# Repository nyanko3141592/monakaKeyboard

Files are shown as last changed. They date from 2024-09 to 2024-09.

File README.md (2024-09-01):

# monakaKeyboard

monakaKeyboard は、自作キーボードのプロジェクトです。このリポジトリには、キーボードの設計ファイル、ファームウェア、キーキャップデザイン、ケースの 3D モデルなどが含まれています。

## プロジェクト構成

```
.
├── 3DModel
│   ├── Case
│   │   ├── bottomboard.stl
│   │   └── topboard.stl
│   └── keycap
│       ├── alphabet_keycap.stl
│       └── symbol_keycap.stl
├── 3x7
├── README.md
└── choco002
    ├── keyboard.json
    ├── keymaps
    │   └── default
    │       └── keymap.c
    └── readme.md
```

### 3DModel

- `Case/`  
  ケースの 3D モデルが含まれています。

  - `bottomboard.stl` - 底板の 3D モデル
  - `topboard.stl` - 上部パネルの 3D モデル

- `keycap/`  
  キーキャップの 3D モデルが含まれています。
  - `alphabet_keycap.stl` - アルファベットキー用キーキャップ
  - `symbol_keycap.stl` - シンボルキー用キーキャップ

### 3x7

3x7 キー配列の設計データが含まれています。
3x7/DisliKey.kicad_pro から kicad で開いて Gerber ファイルを発注することができます。

### choco002

QMK ファームウェアの設定ファイルが含まれています。

- `keyboard.json`  
  キーボードの設定ファイルです。

- `keymaps/`  
  キーマップの定義が含まれています。
  - `default/keymap.c` - デフォルトのキーマップ定義

## 使い方

### 3D モデルの印刷

`3DModel`ディレクトリ内の STL ファイルを 3D プリンターで印刷してください。ケースとキーキャップを含めた全ての部品を印刷することで、物理的なキーボードを組み立てることができます。

### QMK ファームウェアの設定

`choco002`ディレクトリ内のファイルを使用して、QMK ファームウェアをビルドおよびフラッシュします。キーマップはデフォルト設定で使用できますが、`keymap.c`ファイルを編集することでカスタマイズが可能です。

1. QMK CLI をインストールしていない場合は[こちら](https://docs.qmk.fm/#/ja/getting_started_build_tools)からインストールしてください。
2. `choco002`ディレクトリに移動し、次のコマンドを実行します。

   ```
   qmk compile -kb choco002 -km default
   qmk flash -kb choco002 -km default
   ```

## ライセンス

このプロジェクトは、商用利用を除く目的での使用、改変、および出力を許可します。

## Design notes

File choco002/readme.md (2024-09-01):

# choco002

choco002

*A short description of the keyboard/project*

* Keyboard Maintainer: [Naoki Takahashi / 電電猫猫](https://github.com/Naoki Takahashi / 電電猫猫)
* Hardware Supported: *The PCBs, controllers supported*
* Hardware Availability: *Links to where you can find this hardware*

Make example for this keyboard (after setting up your build environment):

    make choco002:default

Flashing example for this keyboard:

    make choco002:default:flash

See the [build environment setup](https://docs.qmk.fm/#/getting_started_build_tools) and the [make instructions](https://docs.qmk.fm/#/getting_started_make_guide) for more information. Brand new to QMK? Start with our [Complete Newbs Guide](https://docs.qmk.fm/#/newbs).

## Bootloader

Enter the bootloader in 3 ways:

* **Bootmagic reset**: Hold down the key at (0,0) in the matrix (usually the top left key or Escape) and plug in the keyboard
* **Physical reset button**: Briefly press the button on the back of the PCB - some may have pads you must short instead
* **Keycode in layout**: Press the key mapped to `QK_BOOT` if it is available

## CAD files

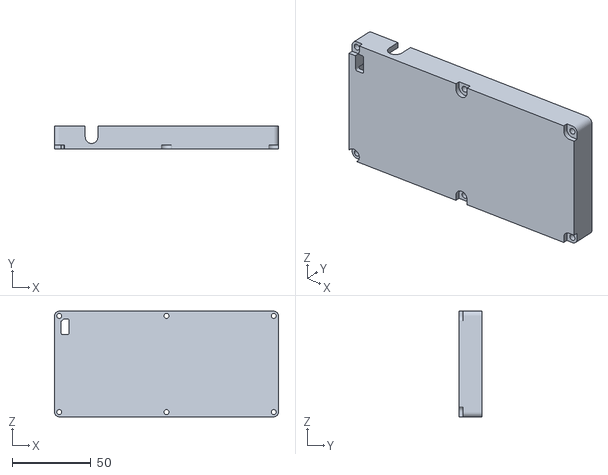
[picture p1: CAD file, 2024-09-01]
3DModel/Case/bottomboard.stl
142.1 x 14.5 x 67.0

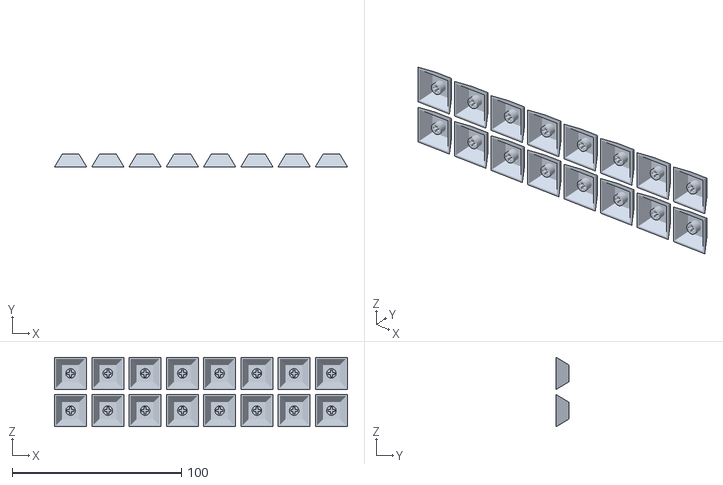
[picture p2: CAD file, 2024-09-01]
3DModel/keycap/symbol_keycap.stl
173.0 x 7.50 x 41.0

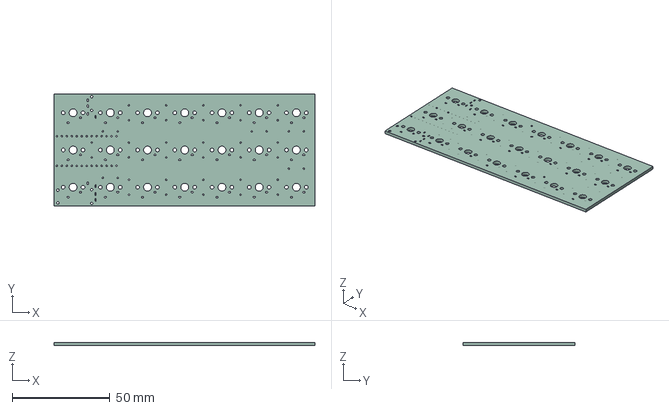
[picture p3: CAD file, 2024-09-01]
3x7/DisliKey.step
133.6 x 57.2 x 1.60 mm

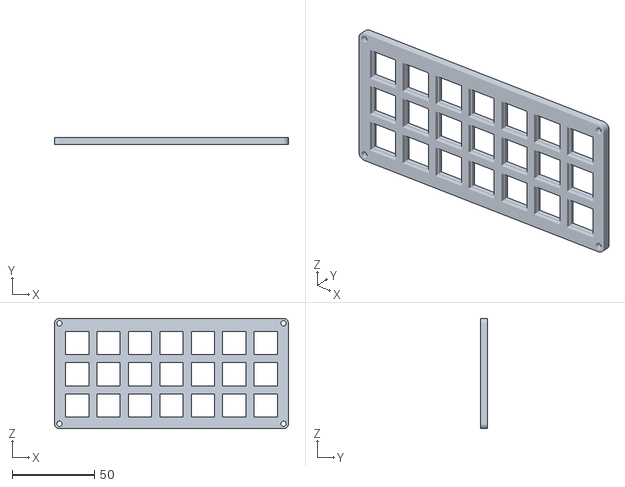
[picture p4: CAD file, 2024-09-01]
3DModel/Case/topboard.stl
142.1 x 4.00 x 67.0

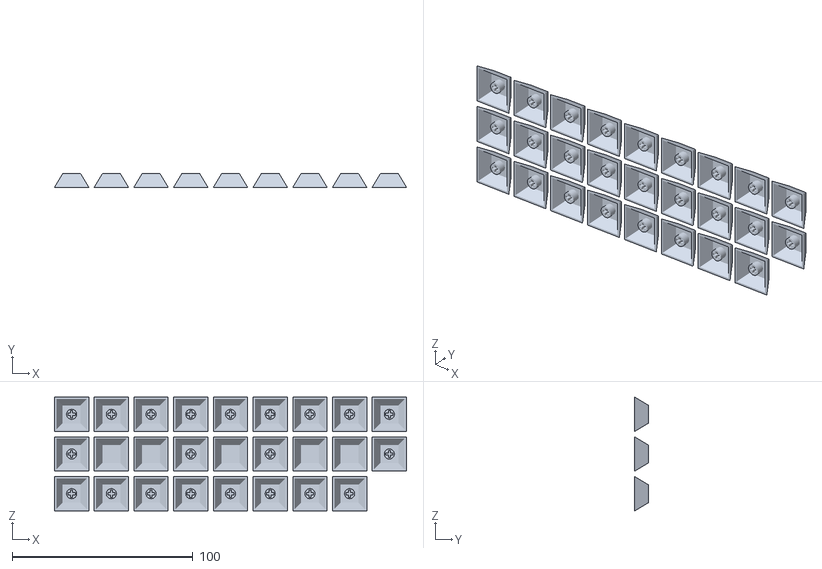
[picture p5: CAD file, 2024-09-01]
3DModel/keycap/alphabet_keycap.stl
195.0 x 7.50 x 63.0

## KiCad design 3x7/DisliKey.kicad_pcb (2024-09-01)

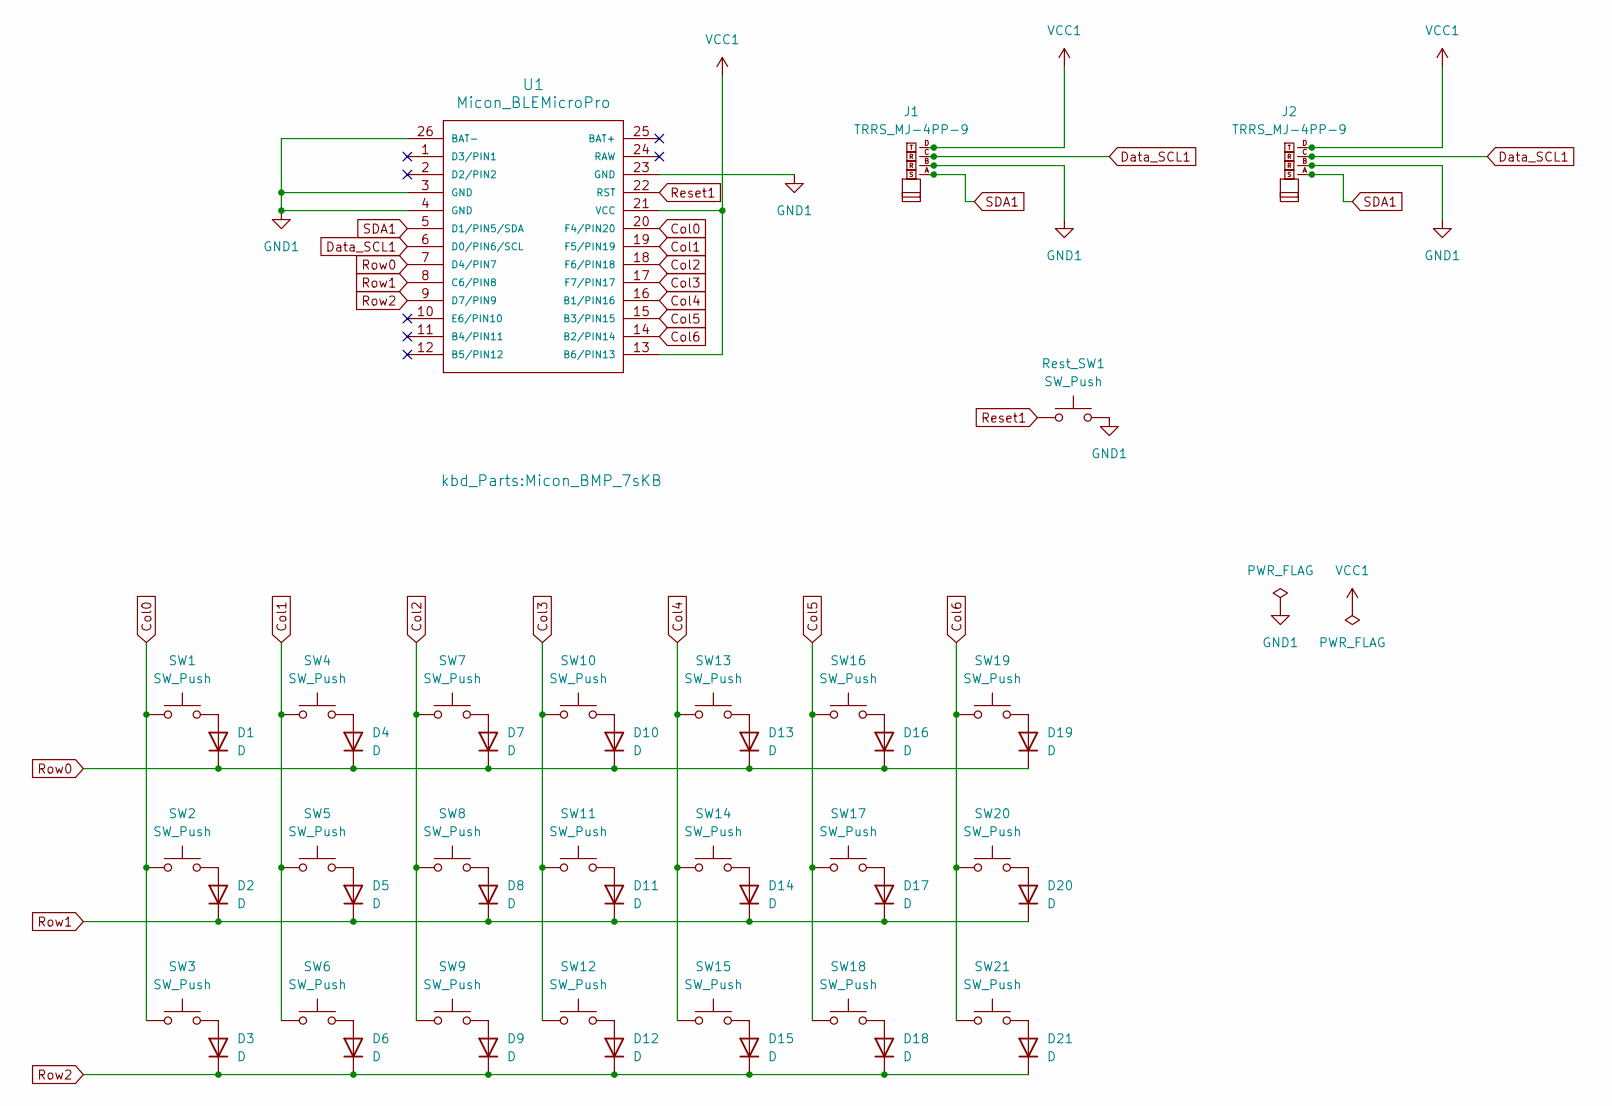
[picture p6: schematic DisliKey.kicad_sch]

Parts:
D1, D2, D3, D4, D5, D6, D7, D8, D9, D10, D11, D12, D13, D14, D15, D16, D17, D18, D19, D20, D21: D; Diode_TH
J1, J2: TRRS_MJ-4PP-9
Rest_SW1: SW_Push; ResetSW
SW1, SW2, SW3, SW4, SW5, SW6, SW7, SW8, SW9, SW10, SW11, SW12, SW13, SW14, SW15, SW16, SW17, SW18, SW19, SW20, SW21: SW_Push; CherryMX_Solder_1u
U1: Micon_BLEMicroPro; Micon_BMP_7sKB

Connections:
Col0: SW1.1, SW2.1, SW3.1, U1.20 (F4/PIN20)
Col1: SW4.1, SW5.1, SW6.1, U1.19 (F5/PIN19)
Col2: SW7.1, SW8.1, SW9.1, U1.18 (F6/PIN18)
Col3: SW10.1, SW11.1, SW12.1, U1.17 (F7/PIN17)
Col4: SW13.1, SW14.1, SW15.1, U1.16 (B1/PIN16)
Col5: SW16.1, SW17.1, SW18.1, U1.15 (B3/PIN15)
Col6: SW19.1, SW20.1, SW21.1, U1.14 (B2/PIN14)
Data_SCL1: J1.C, J2.C, U1.6 (D0/PIN6/SCL)
GND1: J1.B, J2.B, Rest_SW1.2, U1.3 (GND), U1.4 (GND), U1.23 (GND), U1.26 (BAT-)
unnamed: D1.2 (A), SW1.2
unnamed: D2.2 (A), SW2.2
unnamed: D3.2 (A), SW3.2
unnamed: D4.2 (A), SW4.2
unnamed: D5.2 (A), SW5.2
unnamed: D6.2 (A), SW6.2
unnamed: D7.2 (A), SW7.2
unnamed: D8.2 (A), SW8.2
unnamed: D9.2 (A), SW9.2
unnamed: D10.2 (A), SW10.2
unnamed: D11.2 (A), SW11.2
unnamed: D12.2 (A), SW12.2
unnamed: D13.2 (A), SW13.2
unnamed: D14.2 (A), SW14.2
unnamed: D15.2 (A), SW15.2
unnamed: D16.2 (A), SW16.2
unnamed: D17.2 (A), SW17.2
unnamed: D18.2 (A), SW18.2
unnamed: D19.2 (A), SW19.2
unnamed: D20.2 (A), SW20.2
unnamed: D21.2 (A), SW21.2
Reset1: Rest_SW1.1, U1.22 (RST)
Row0: D1.1 (K), D4.1 (K), D7.1 (K), D10.1 (K), D13.1 (K), D16.1 (K), D19.1 (K), U1.7 (D4/PIN7)
Row1: D2.1 (K), D5.1 (K), D8.1 (K), D11.1 (K), D14.1 (K), D17.1 (K), D20.1 (K), U1.8 (C6/PIN8)
Row2: D3.1 (K), D6.1 (K), D9.1 (K), D12.1 (K), D15.1 (K), D18.1 (K), D21.1 (K), U1.9 (D7/PIN9)
SDA1: J1.A, J2.A, U1.5 (D1/PIN5/SDA)
VCC1: J1.D, J2.D, U1.13 (B6/PIN13), U1.21 (VCC)

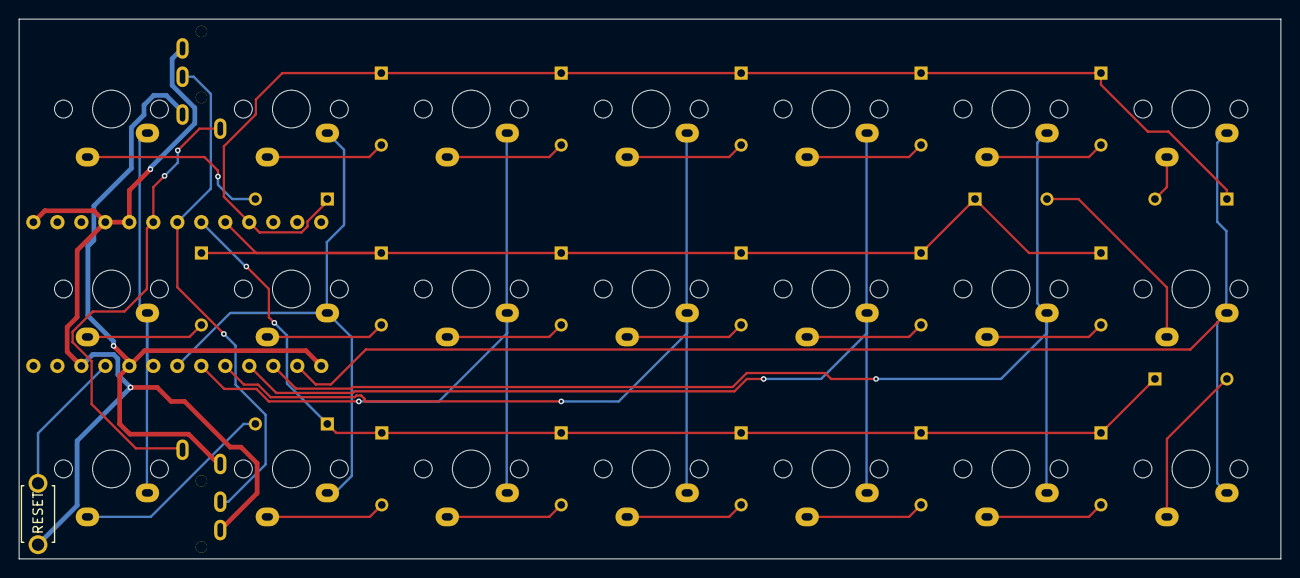
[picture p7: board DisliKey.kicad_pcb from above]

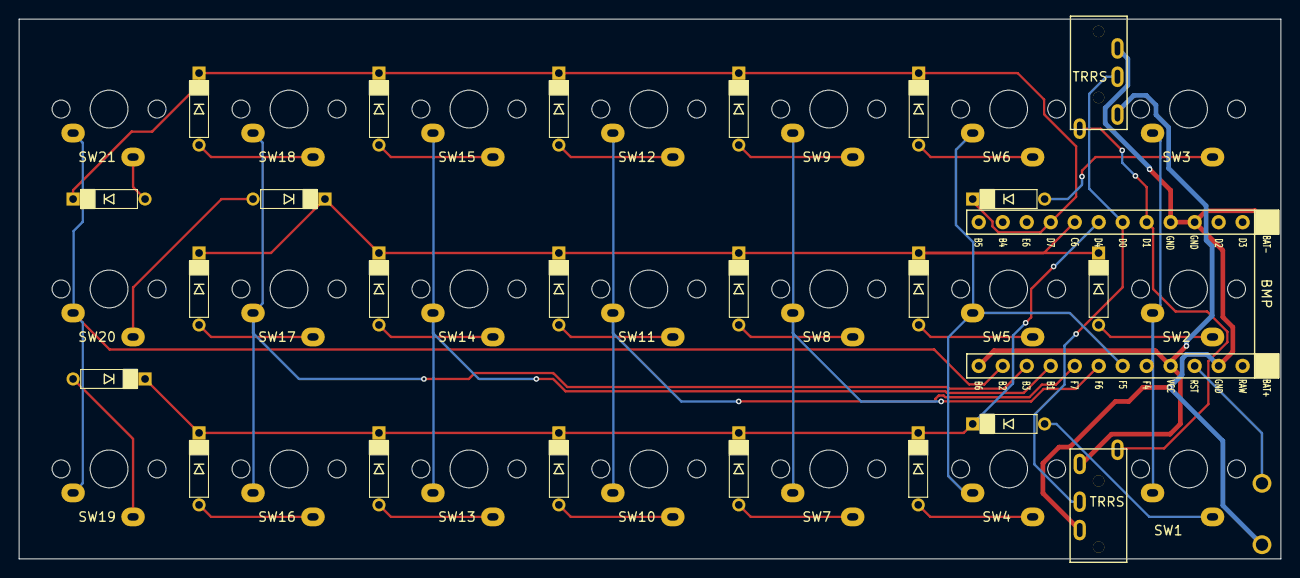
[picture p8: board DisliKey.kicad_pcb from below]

Board: 2 copper layers, 133.6 x 57.2 mm, 46 parts (2 on the bottom side), 36 nets.
